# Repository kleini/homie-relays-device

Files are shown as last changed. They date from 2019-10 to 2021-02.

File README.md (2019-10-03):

# Relays device for controlling arbitrary loads

## Concept

ESP8266 based controller using Homie and a I/O Extender to control 16 relays. Everything should fit in a DIN Rail Standard Height Module Box.

## Hardware

 * ESP8266 12e module
 * I²C I/O Extender MCP23016 (16 GPIOs)
 * self designed board fitting into DIN Rail Standard Height Module Box (see hardware branch)
 * 230V power supply

I²C device address configured to 0x20.

DCDC converter from 12V down to 3.3V running ESP8266 and MCP23016. Some driver chip will be used to drive the relay coils.

Every output will have its own indicator LED.

### MCP23016

This chip is able to drive a LED directly on the high output.

### Lessons learned

#### PCF8575

The PCF8575 has only a very low continuous output high current of -4mA. This allows possibly to light up a low current LED but not much more. Will drop the use of this chip and use something with higher output high current.

## Case

Everything should fit in a DIN Rail Standard Module Box like the following
DIN Rail Standard Height Module Box

The design of the printed circuit board will finally show, how much relays I can fit in which box. Current design goal is to have a 3 module wide box. If I can not fit 16 230V 5A relays switches onto the PCB in this box,
I will take a wider box.

The box can carry up to 3 PCBs. I will use only 2, a large one in the bottom for power supply and relays switches and a smaller one in the top for ESP8266, indicator LEDs and I/O expander.

## Compiling

Software will be based on latest homie-esp8266 development cycle.

Extended/modified libraries are necessary.

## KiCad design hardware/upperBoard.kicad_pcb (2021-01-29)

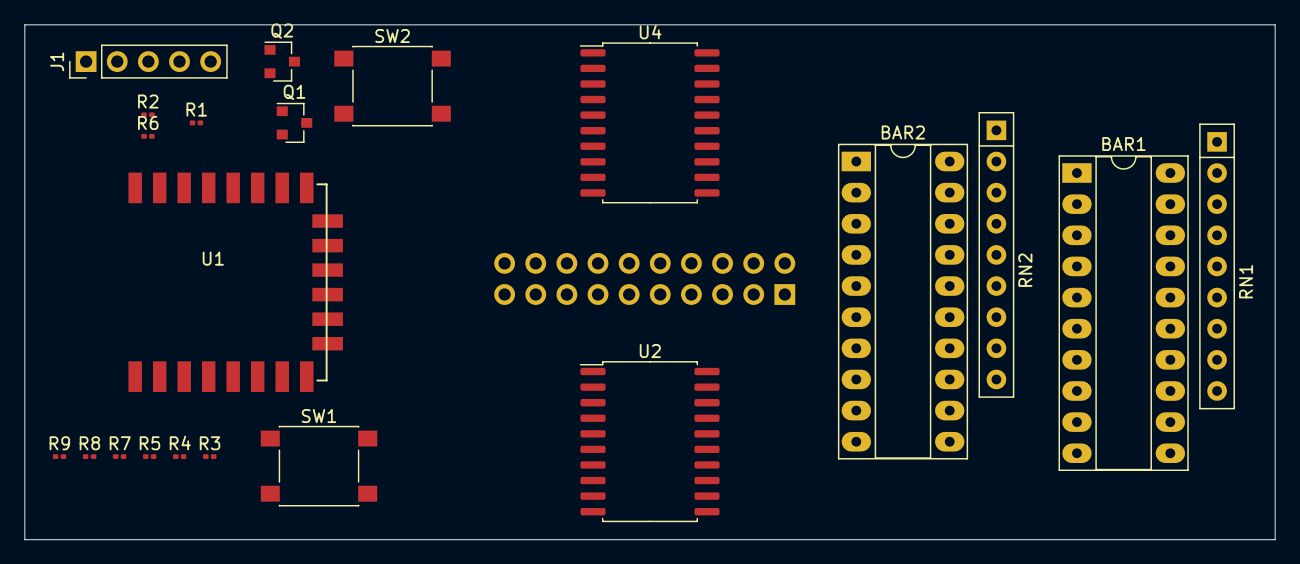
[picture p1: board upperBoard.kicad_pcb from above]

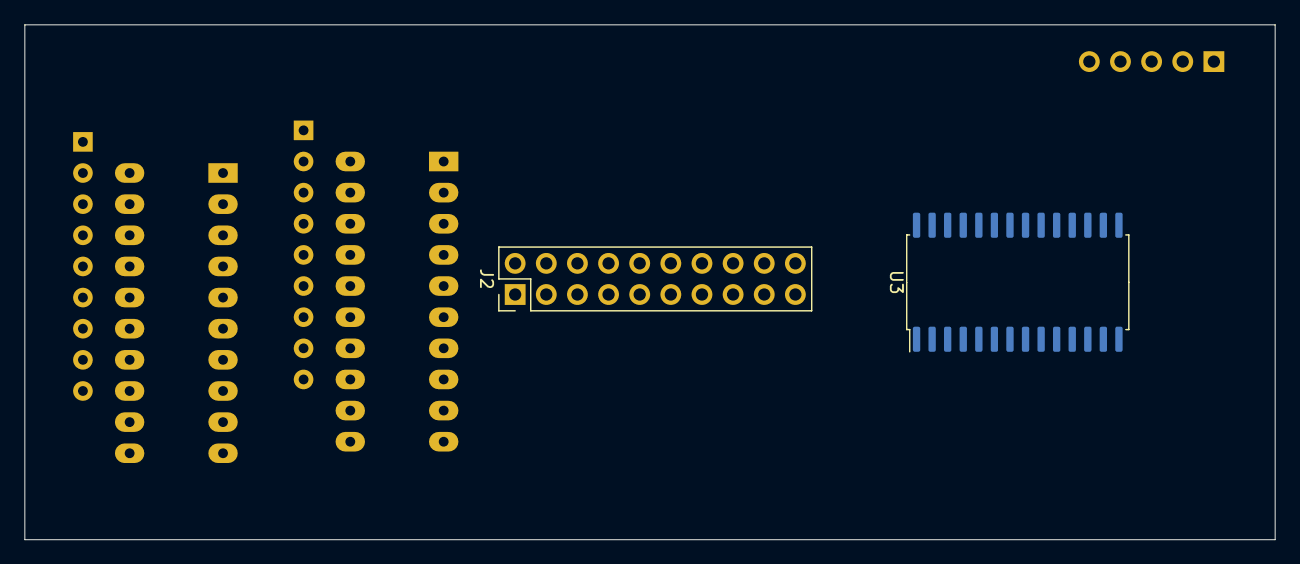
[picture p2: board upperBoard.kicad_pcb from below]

Board: 2 copper layers, 102.0 x 42.0 mm, 23 parts (2 on the bottom side), 64 nets, no tracks yet.

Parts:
BAR1, BAR2: HDSP-4830_2; DIP-20_W7.62mm_Socket_LongPads
J1: Program interface; PinHeader_1x05_P2.54mm_Vertical
J2: Conn_02x10_Odd_Even; PinHeader_2x10_P2.54mm_Vertical
Q1, Q2: MMBT3904; SOT-23
R1, R2, R3, R4, R6, R7, R8, R9: 10K; R_0201_0603Metric
R5: 4.7K; R_0201_0603Metric
RN1: 150; R_Array_SIP9
RN2: R_Network08; R_Array_SIP9
SW1: Reset; SW_Push_1P1T_NO_6x6mm_H9.5mm
SW2: Prog; SW_Push_1P1T_NO_6x6mm_H9.5mm
U1: ESP-12F; ESP-12E_SMD
U2, U4: A2982; SOIC-20W_7.5x12.8mm_P1.27mm
U3: MCP23017_SO; SOIC-28W_7.5x17.9mm_P1.27mm

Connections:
/01: J2.15, U2.20
/02: J2.13, U2.19
/03: J2.11, U2.18
/3.3V: J2.17, R1.1, R2.1, R6.1, R7.1, R8.1, R9.1, U1.8, U3.9
/04: J2.9, U2.17
/05: J2.7, U2.16
/06: J2.5, U2.15
/07: J2.3, U2.14
/08: J2.1, U2.13
/09: J2.2, U4.20
/10: J2.4, U4.19
/11: J2.6, U4.18
/12: J2.8, U4.17
/12V: J2.19, U2.9, U4.9
/13: J2.10, U4.16
/14: J2.12, U4.15
/15: J2.14, U4.14
/16: J2.16, U4.13
/DTR: J1.3, Q2.2, R3.1
/GND: J1.5, J2.18, J2.20, R5.2, RN1.1, RN2.1, SW1.1, SW2.2, U1.9, U2.12, U3.10, U3.15, U3.16, U3.17, U4.12
/RTS: J1.4, Q1.2, R4.1
/RXD: J1.1, U1.16
/TXD: J1.2, U1.15
unnamed: BAR1.1, U2.1, U3.21
unnamed: BAR1.2, U2.2, U3.22
unnamed: BAR1.3, U2.3, U3.23
unnamed: BAR1.4, U2.4, U3.24
unnamed: BAR1.5, U2.5, U3.25
unnamed: BAR1.6, U2.6, U3.26
unnamed: BAR1.7, U2.7, U3.27
unnamed: BAR1.8, U2.8, U3.28
unnamed: BAR1.13, RN1.9
unnamed: BAR1.14, RN1.8
unnamed: BAR1.15, RN1.7
unnamed: BAR1.16, RN1.6
unnamed: BAR1.17, RN1.5
unnamed: BAR1.18, RN1.4
unnamed: BAR1.19, RN1.3
unnamed: BAR1.20, RN1.2
unnamed: BAR2.1, U3.1, U4.1
unnamed: BAR2.2, U3.2, U4.2
unnamed: BAR2.3, U3.3, U4.3
unnamed: BAR2.4, U3.4, U4.4
unnamed: BAR2.5, U3.5, U4.5
unnamed: BAR2.6, U3.6, U4.6
unnamed: BAR2.7, U3.7, U4.7
unnamed: BAR2.8, U3.8, U4.8
unnamed: BAR2.13, RN2.9
unnamed: BAR2.14, RN2.8
unnamed: BAR2.15, RN2.7
unnamed: BAR2.16, RN2.6
unnamed: BAR2.17, RN2.5
unnamed: BAR2.18, RN2.4
unnamed: BAR2.19, RN2.3
unnamed: BAR2.20, RN2.2
unnamed: Q1.1, R3.2
unnamed: Q1.3, R1.2, SW1.2, U1.1, U3.18
unnamed: Q2.1, R4.2
unnamed: Q2.3, R6.2, SW2.1, U1.12
unnamed: R2.2, U1.3
unnamed: R5.1, U1.10
unnamed: R7.2, U1.14, U3.12
unnamed: R8.2, U1.13, U3.13
unnamed: R9.2, U1.11

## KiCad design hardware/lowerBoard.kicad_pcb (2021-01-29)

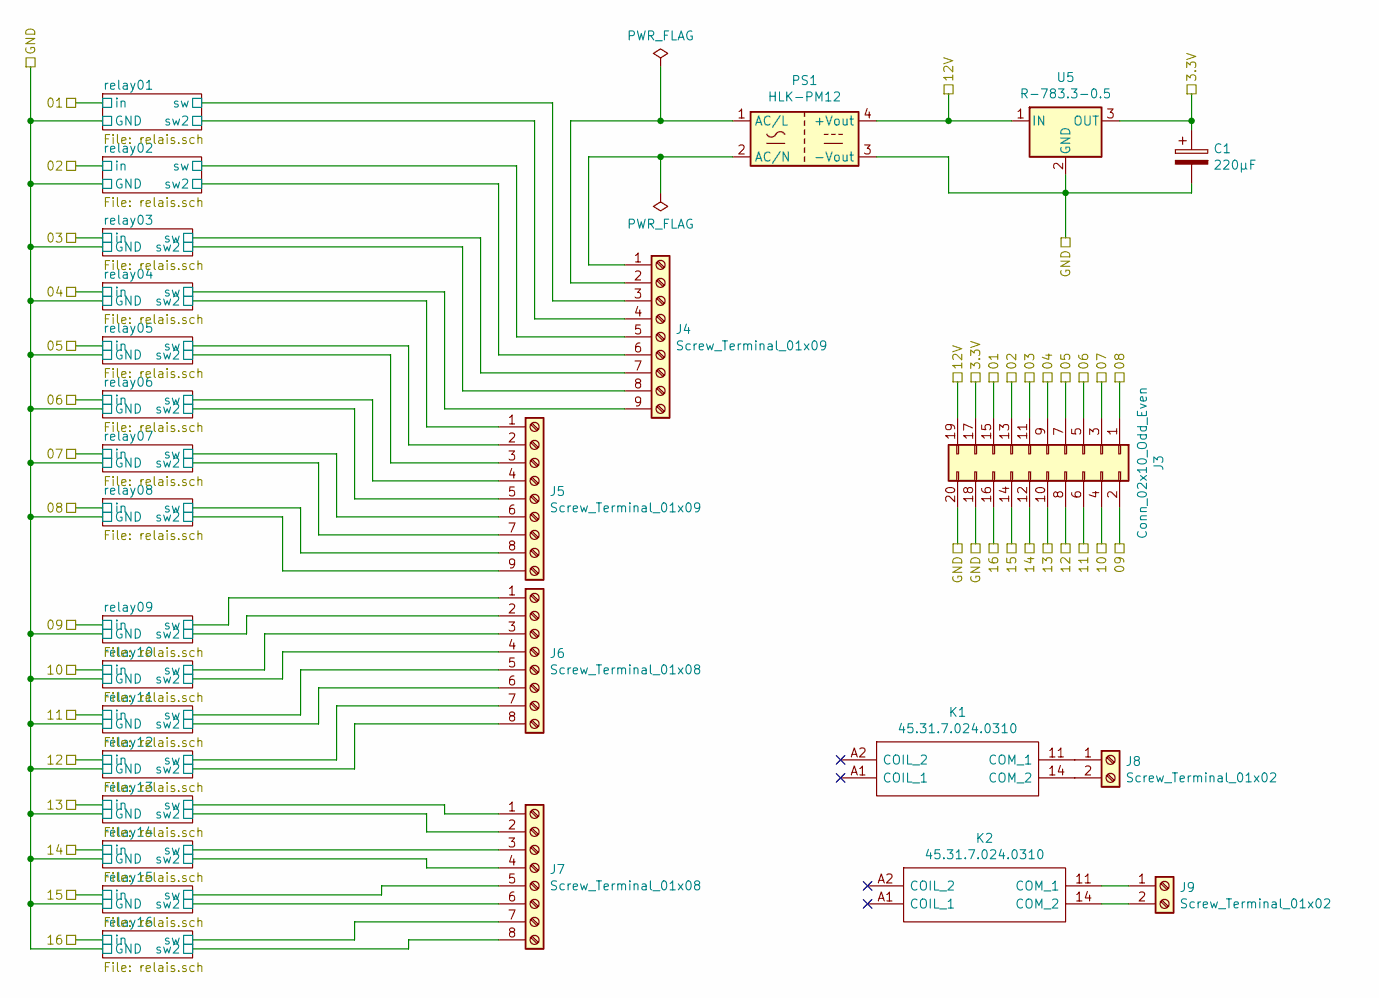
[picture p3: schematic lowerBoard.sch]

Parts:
C1: 220µF; CP_Radial_D6.3mm_P2.50mm
J3: Conn_02x10_Odd_Even; PinHeader_2x10_P2.54mm_Vertical
J4, J5: Screw_Terminal_01x09; TerminalBlock_RND_205-00239_1x09_P5.08mm_Horizontal
J6, J7: Screw_Terminal_01x08; TerminalBlock_RND_205-00238_1x08_P5.08mm_Horizontal
J8, J9: Screw_Terminal_01x02; TerminalBlock_MetzConnect_Type101_RT01602HBWC_1x02_P5.08mm_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
K1, K2: 45.31.7.024.0310; finder-45.31.7.024.0310; Manufacturer_Part_Number 45.31.7.024.0310
PS1: HLK-PM12; Converter_ACDC_HiLink_HLK-PMxx
U5: R-783.3-0.5; Converter_DCDC_RECOM_R-78E-0.5_THT

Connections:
/01: J3.15; also elsewhere on the board
/02: J3.13; also elsewhere on the board
/03: J3.11; also elsewhere on the board
/3.3V: C1.1, J3.17, U5.3 (OUT)
/04: J3.9; also elsewhere on the board
/05: J3.7; also elsewhere on the board
/06: J3.5; also elsewhere on the board
/07: J3.3; also elsewhere on the board
/08: J3.1; also elsewhere on the board
/09: J3.2; also elsewhere on the board
/10: J3.4; also elsewhere on the board
/11: J3.6; also elsewhere on the board
/12: J3.8; also elsewhere on the board
/12V: J3.19, PS1.4 (+Vout), U5.1 (IN)
/13: J3.10; also elsewhere on the board
/14: J3.12; also elsewhere on the board
/15: J3.14; also elsewhere on the board
/16: J3.16; also elsewhere on the board
/GND: C1.2, J3.18, J3.20, PS1.3 (-Vout), U5.2 (GND); also elsewhere on the board
/relay01/sw: J4.3; also elsewhere on the board
/relay01/sw2: J4.4; also elsewhere on the board
/relay02/sw: J4.5; also elsewhere on the board
/relay02/sw2: J4.6; also elsewhere on the board
/relay03/sw: J4.7; also elsewhere on the board
/relay03/sw2: J4.8; also elsewhere on the board
/relay04/sw: J4.9; also elsewhere on the board
/relay04/sw2: J5.1; also elsewhere on the board
/relay05/sw: J5.2; also elsewhere on the board
/relay05/sw2: J5.3; also elsewhere on the board
/relay06/sw: J5.4; also elsewhere on the board
/relay06/sw2: J5.5; also elsewhere on the board
/relay07/sw: J5.6; also elsewhere on the board
/relay07/sw2: J5.7; also elsewhere on the board
/relay08/sw: J5.8; also elsewhere on the board
/relay08/sw2: J5.9; also elsewhere on the board
/relay09/sw: J6.1; also elsewhere on the board
/relay09/sw2: J6.2; also elsewhere on the board
/relay10/sw: J6.3; also elsewhere on the board
/relay10/sw2: J6.4; also elsewhere on the board
/relay11/sw: J6.5; also elsewhere on the board
/relay11/sw2: J6.6; also elsewhere on the board
/relay12/sw: J6.7; also elsewhere on the board
/relay12/sw2: J6.8; also elsewhere on the board
/relay13/sw: J7.1; also elsewhere on the board
/relay13/sw2: J7.2; also elsewhere on the board
/relay14/sw: J7.3; also elsewhere on the board
/relay14/sw2: J7.4; also elsewhere on the board
/relay15/sw: J7.5; also elsewhere on the board
/relay15/sw2: J7.6; also elsewhere on the board
/relay16/sw: J7.7; also elsewhere on the board
/relay16/sw2: J7.8; also elsewhere on the board
unnamed: J4.1, PS1.2 (AC/N)
unnamed: J4.2, PS1.1 (AC/L)
unnamed: J8.1, K1.11 (COM_1)
unnamed: J8.2, K1.14 (COM_2)
unnamed: J9.1, K2.11 (COM_1)
unnamed: J9.2, K2.14 (COM_2)

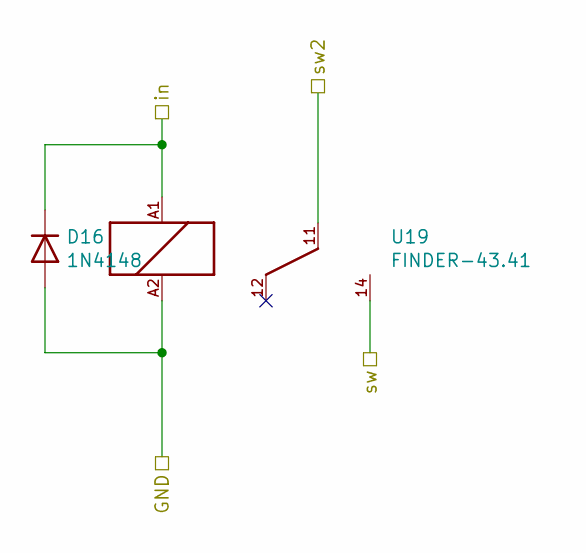
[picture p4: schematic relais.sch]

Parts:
D2: 1N4148; D_DO-35_SOD27_P7.62mm_Horizontal
U7: FINDER-43.41; finder-43.41

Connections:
/02: D2.1 (K), U7.A1; also elsewhere on the board
/GND: D2.2 (A), U7.A2; also elsewhere on the board
/relay02/sw: U7.14; also elsewhere on the board
/relay02/sw2: U7.11; also elsewhere on the board

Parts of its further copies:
D1, D3, D4, D5, D6, D7, D8, D9, D10, D11, D12, D13, D14, D15, D16: 1N4148; D_DO-35_SOD27_P7.62mm_Horizontal
U6, U8, U9, U10, U11, U12, U13, U14, U15, U16, U17, U18, U19, U20, U21: FINDER-43.41; finder-43.41

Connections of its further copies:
/01: D1.1 (K), U6.A1; also elsewhere on the board
/03: D3.1 (K), U8.A1; also elsewhere on the board
/04: D4.1 (K), U9.A1; also elsewhere on the board
/05: D5.1 (K), U10.A1; also elsewhere on the board
/06: D6.1 (K), U11.A1; also elsewhere on the board
/07: D7.1 (K), U12.A1; also elsewhere on the board
/08: D8.1 (K), U13.A1; also elsewhere on the board
/09: D9.1 (K), U14.A1; also elsewhere on the board
/10: D10.1 (K), U15.A1; also elsewhere on the board
/11: D11.1 (K), U16.A1; also elsewhere on the board
/12: D12.1 (K), U17.A1; also elsewhere on the board
/13: D13.1 (K), U18.A1; also elsewhere on the board
/14: D16.1 (K), U19.A1; also elsewhere on the board
/15: D14.1 (K), U20.A1; also elsewhere on the board
/16: D15.1 (K), U21.A1; also elsewhere on the board
/GND: D1.2 (A), D3.2 (A), D4.2 (A), D5.2 (A), D6.2 (A), D7.2 (A), D8.2 (A), D9.2 (A), D10.2 (A), D11.2 (A), D12.2 (A), D13.2 (A), D14.2 (A), D15.2 (A), D16.2 (A), U6.A2, U8.A2, U9.A2, U10.A2, U11.A2, U12.A2, U13.A2, U14.A2, U15.A2, U16.A2, U17.A2, U18.A2, U19.A2, U20.A2, U21.A2; also elsewhere on the board
/relay01/sw: U6.14; also elsewhere on the board
/relay01/sw2: U6.11; also elsewhere on the board
/relay03/sw: U8.14; also elsewhere on the board
/relay03/sw2: U8.11; also elsewhere on the board
/relay04/sw: U9.14; also elsewhere on the board
/relay04/sw2: U9.11; also elsewhere on the board
/relay05/sw: U10.14; also elsewhere on the board
/relay05/sw2: U10.11; also elsewhere on the board
/relay06/sw: U11.14; also elsewhere on the board
/relay06/sw2: U11.11; also elsewhere on the board
/relay07/sw: U12.14; also elsewhere on the board
/relay07/sw2: U12.11; also elsewhere on the board
/relay08/sw: U13.14; also elsewhere on the board
/relay08/sw2: U13.11; also elsewhere on the board
/relay09/sw: U14.14; also elsewhere on the board
/relay09/sw2: U14.11; also elsewhere on the board
/relay10/sw: U15.14; also elsewhere on the board
/relay10/sw2: U15.11; also elsewhere on the board
/relay11/sw: U16.14; also elsewhere on the board
/relay11/sw2: U16.11; also elsewhere on the board
/relay12/sw: U17.14; also elsewhere on the board
/relay12/sw2: U17.11; also elsewhere on the board
/relay13/sw: U18.14; also elsewhere on the board
/relay13/sw2: U18.11; also elsewhere on the board
/relay14/sw: U19.14; also elsewhere on the board
/relay14/sw2: U19.11; also elsewhere on the board
/relay15/sw: U20.14; also elsewhere on the board
/relay15/sw2: U20.11; also elsewhere on the board
/relay16/sw: U21.14; also elsewhere on the board
/relay16/sw2: U21.11; also elsewhere on the board

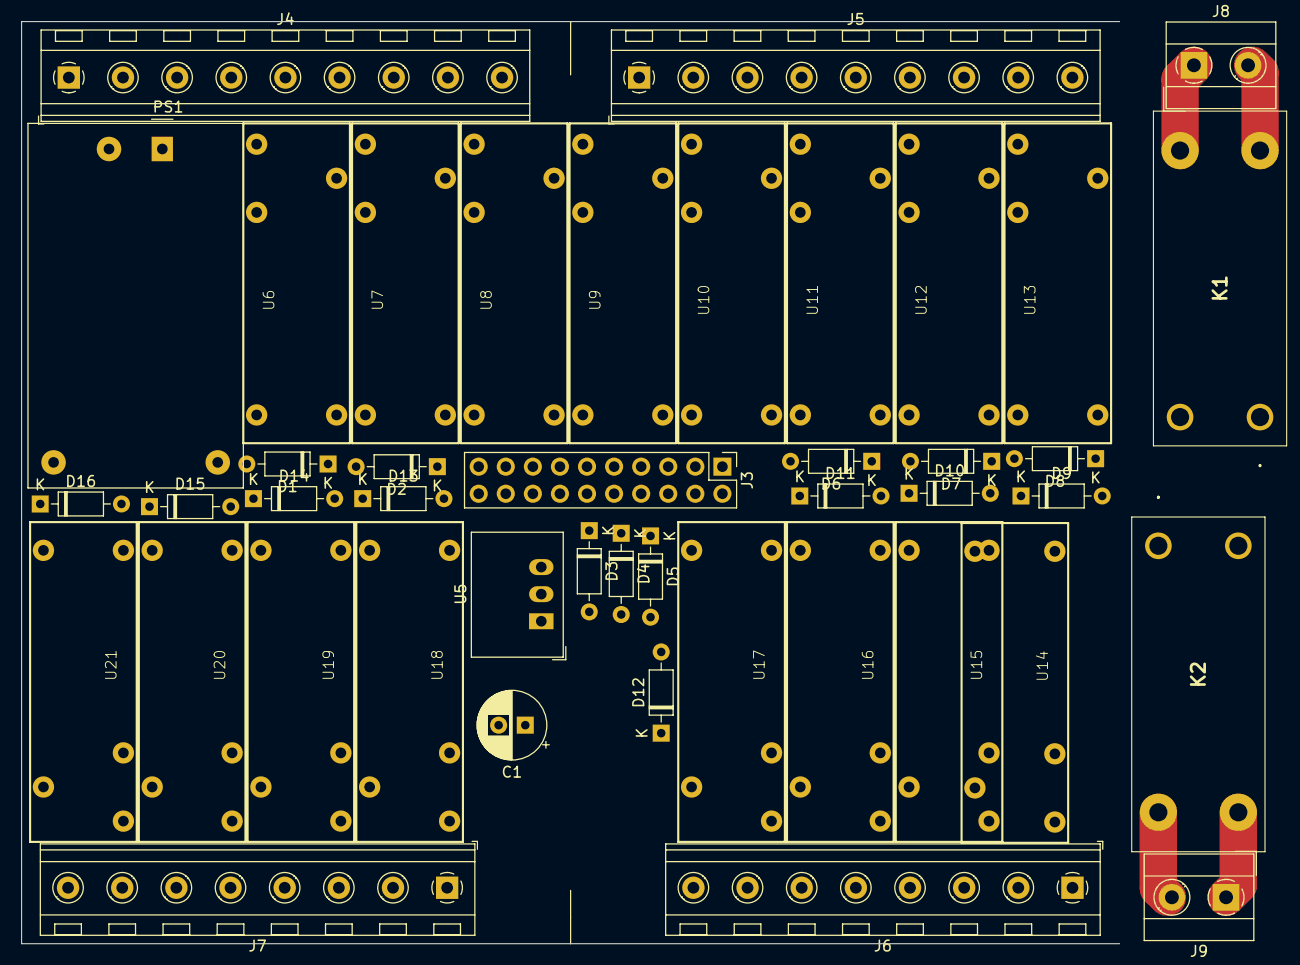
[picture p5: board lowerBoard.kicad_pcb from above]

Board: 2 copper layers, 103.0 x 86.5 mm, 44 parts (0 on the bottom side), 57 nets.

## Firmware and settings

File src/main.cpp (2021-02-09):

#define FW_NAME "relays-device"
#define FW_VERSION "0.0.11"

#include "Homie.h"
#include <Wire.h>
#include <Adafruit_MCP23017.h>

#include "AdcNode.hpp"

// internal LED of ESP8266-12E/F is connected to GPIO2
const int PIN_LED = 2;

Adafruit_MCP23017 mcp;

ADC_MODE(ADC_VCC); // Set ADC to measure internal VCC
AdcNode adcNode("adc", "Internal", 30 * 1000);

void setup() {
  Serial.begin(115200);
  Serial << endl << endl;

  mcp.begin();
  for (int i = 0; i < 16; i++) {
    mcp.pinMode(i, OUTPUT);
  }

  adcNode.beforeHomieSetup();

  pinMode(PIN_LED, OUTPUT);

  Homie_setFirmware(FW_NAME, FW_VERSION);
  // Configuration mode removed with compile flags.
  Homie.disableResetTrigger();
  Homie.setLedPin(PIN_LED, LOW);

  Homie.setup();
}

unsigned long _lastHeapTime;
byte leds = 0;

void loop() {
  if (millis() - _lastHeapTime > 30000) {
    Homie.getLogger() << F("Heap: ") << ESP.getFreeHeap() << endl;
      leds++;
      for (int i = 0; i < 8; i++) {
        if ((leds & (1<<i)) != 0) {
          mcp.digitalWrite(i, HIGH);
        } else {
          mcp.digitalWrite(i, LOW);
        }
      }
    _lastHeapTime = millis();
  }
  Homie.loop();
}

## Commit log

2019-09-26 basic Homie device setup
2019-09-26 started to create schematic for hardware
    [heating-control.kicad_pcb, heating-control.sch]
2019-09-27 corrected N channel MOSFET transistor
2019-09-27 added programming interface
    [heating-control.sch]
2019-09-27 a lot of progress in hardware design
    separated different board into separate hierarchical schematics
    hierarchical schematics for parts to be multiplied
    separate project files for each board for creating separate PCBs without interconnection
    [heating-control.sch, ledAndDriver.sch, lowerBoard.sch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]
2019-09-27 removed useless directory
    [heating-control.kicad_pcb, heating-control.sch, ledAndDriver.sch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]
2019-10-02 started to replace PCF8575 with MCP23016 and separated LEDs with arrays
    [heating-control.sch, ledAndDriver.sch, lowerBoard.sch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]
2019-10-03 correct name relays
2019-10-03 renamed hardware files
    [heating-control.kicad_pcb, relays-device.sch, upperBoard.sch]
2019-10-03 replaced separated driver parts with driver chips and LED bars
    [ledAndDriver.sch, lowerBoard.sch, relays-device.sch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]
2019-10-08 extracted relay to sub schematic to be able to multiply it
    [lowerBoard.sch, relais.sch, relays-device.sch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]
2019-10-19 finished schematic mostly
    started to create lower PCB
    [lowerBoard.kicad_pcb, lowerBoard.sch, relais.sch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]
2020-01-14 upgraded libraries and tested nemidiys fix for not working OTA
    [main.cpp]
2020-12-27 add ADC node
    upgrade to fix branch of async-mqtt-client
    upgrade to latest espressif8266
    [main.cpp]
2021-01-11 started to replace MCP23016 with MCP23017
    [ledAndDriver.sch, lowerBoard.sch, relais.sch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]
2021-01-14 replaced MCP23016 with MCP23017
    [lowerBoard.sch, relais.sch, upperBoard.sch]
2021-01-14 some settings for KiCad
2021-01-21 prototype picture
2021-01-21 schematic picture
2021-01-21 lower board fixes and started with upper printed circuit board
    [lowerBoard.sch, relais.sch, upperBoard.kicad_pcb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]
2021-01-27 continue to design lower pcb
    [lowerBoard.kicad_pcb, lowerBoard.sch, relais.sch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]
2021-01-29 move on to 16A relays
    [lowerBoard.kicad_pcb, lowerBoard.sch, relais.sch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]
